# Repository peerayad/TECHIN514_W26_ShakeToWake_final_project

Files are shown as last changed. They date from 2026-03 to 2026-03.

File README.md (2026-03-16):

# TECHIN514_W26 Final Project
# Shake to Wake

> An alarm clock that **forces you out of bed** — the alarm won't stop until you've moved enough

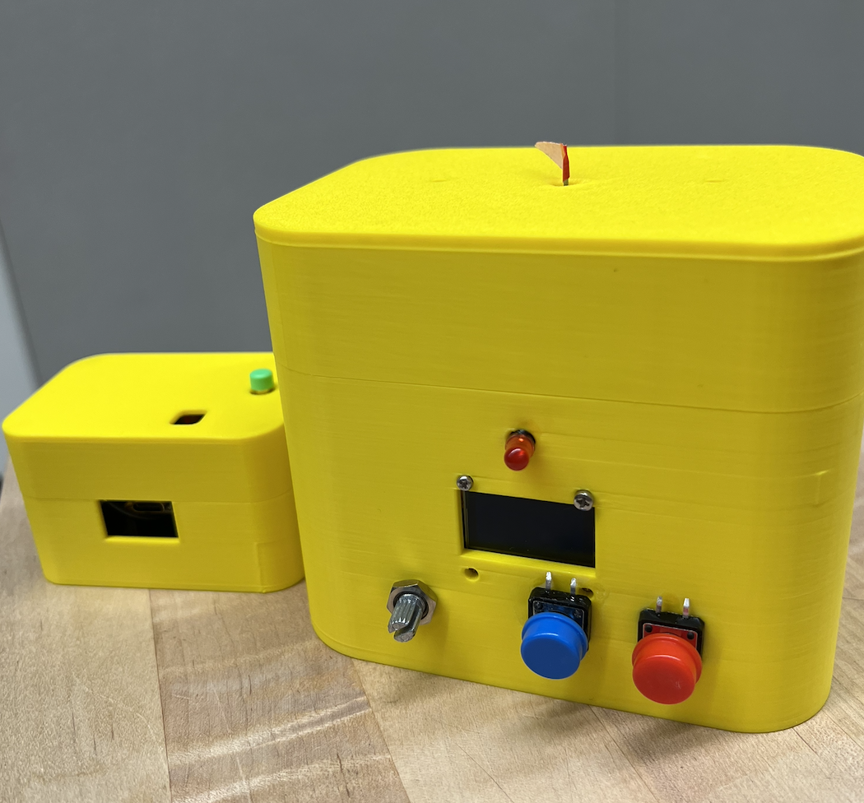
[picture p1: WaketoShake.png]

---

## 📦 Repository Structure
 
```
smart-alarm-clock/
├── alarm_unit/                  # Bedside alarm unit firmware (XIAO ESP32-C3)
│   ├── src/main.cpp
│   └── platformio.ini
├── sensor_unit/                 # sensor firmware (XIAO ESP32-C3)
│   ├── src/main.cpp
│   └── platformio.ini
├── datasheet/                   # Component datasheets
│   ├── ADXL345.pdf
│   ├── LED.pdf
│   ├── Passive_Buzzer.pdf
│   ├── Potentiometer.pdf
│   ├── Push_button.pdf
│   ├── SSD1306.pdf
│   ├── Tactile_switch.pdf
│   └── X27.pdf
├── hardware/
│   ├── Files/                   # Source design files
│   │   ├── Disclosure/          # Disclosure documents
│   │   ├── PCB/                 # KiCad PCB layout files
│   │   ├── Schematic/           # KiCad schematic files
│   │   └── BOM.numbers          # Bill of Materials
│   └── Picture/                 # Rendered images
│       ├── BOM.png
│       ├── Display_3D.png
│       ├── Display_circuit.png
│       ├── Display_disclosure.png
│       ├── PCB layput.png
│       ├── Schematic.png
│       ├── Sensor_3D.png
│       ├── Sensor_circuit.png
│       └── Sensor_disclosure.png
└── README.md
```

---

## 🔧 Hardware Overview

### Device 1 — Motion Sensor

A  sensor device that detects motion and transmits data wirelessly to the bedside alarm unit via ESP-NOW.

| Component | Part | Notes |
|---|---|---|
| Microcontroller | Seeed Studio XIAO ESP32-C3 | ESP-NOW wireless TX |
| Accelerometer | ADXL345 3-axis | Motion detection via I²C |
| Battery | 3.7V 500mAh LiPo

**How it works:**
1. ADXL345 reads 3-axis acceleration every 100ms
2. Adaptive DSP pipeline processes raw data:
   - **Delta Magnitude** — L1-norm: `|ΔX| + |ΔY| + |ΔZ|`
   - **SMA Filter (N=10)** — 10-sample rolling average, removes sensor noise
   - **Baseline Calibration** — collects 10 samples at alarm start, computes `threshold = μ + 3σ`
   - **Adaptive Threshold** — auto-calibrated per device and orientation
3. Broadcasts motion packet to alarm unit via ESP-NOW every 100ms

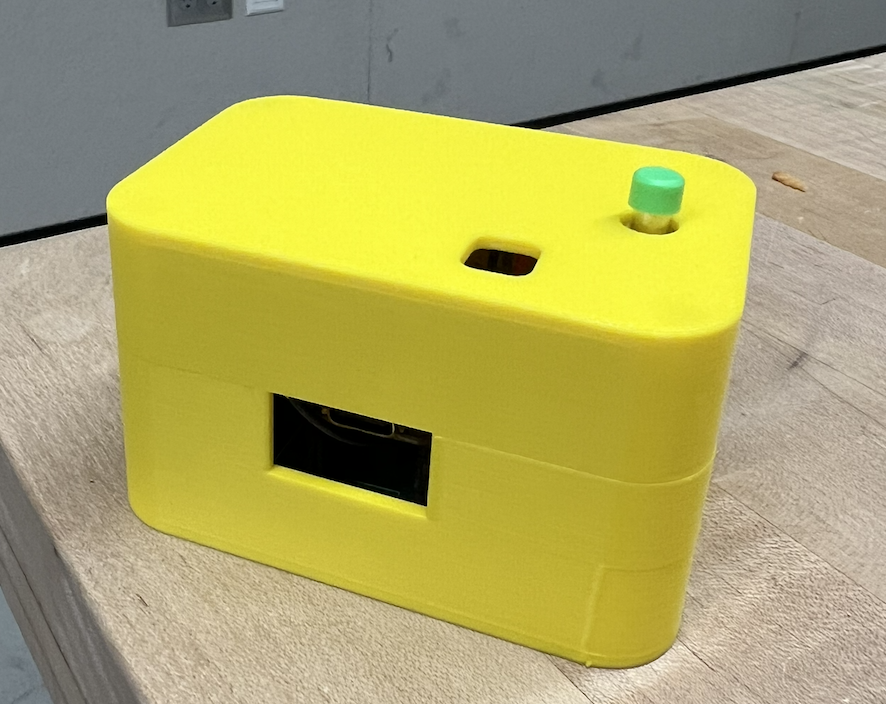
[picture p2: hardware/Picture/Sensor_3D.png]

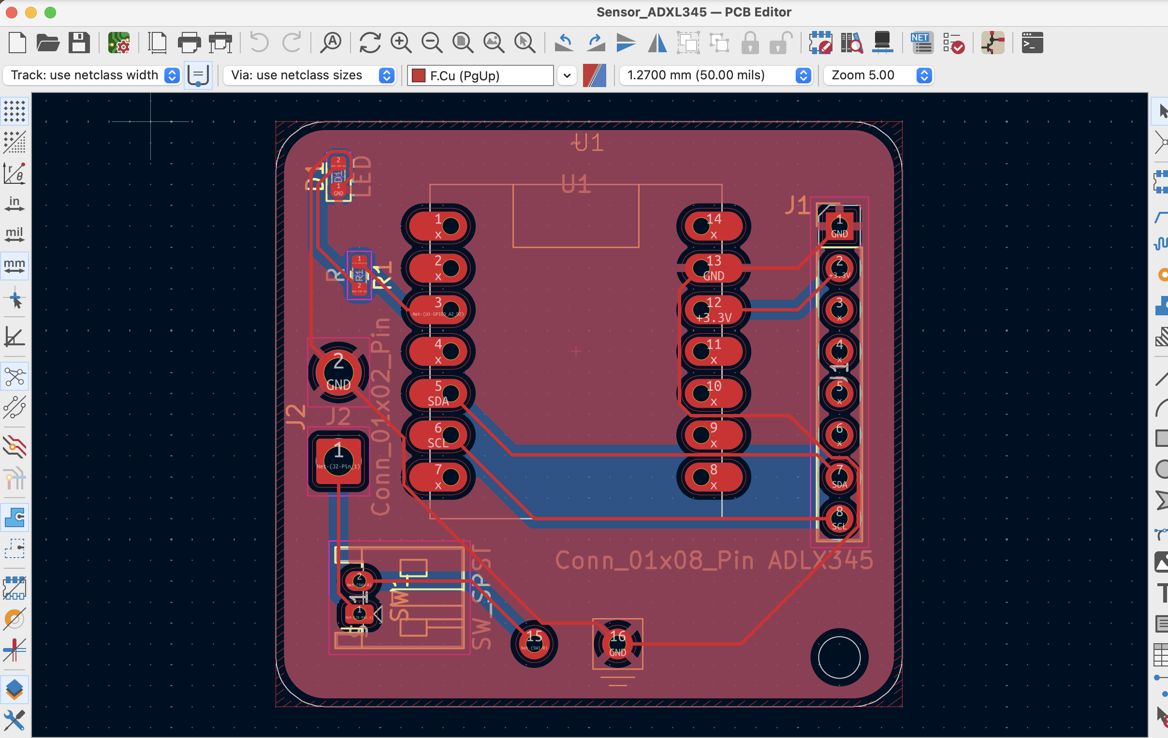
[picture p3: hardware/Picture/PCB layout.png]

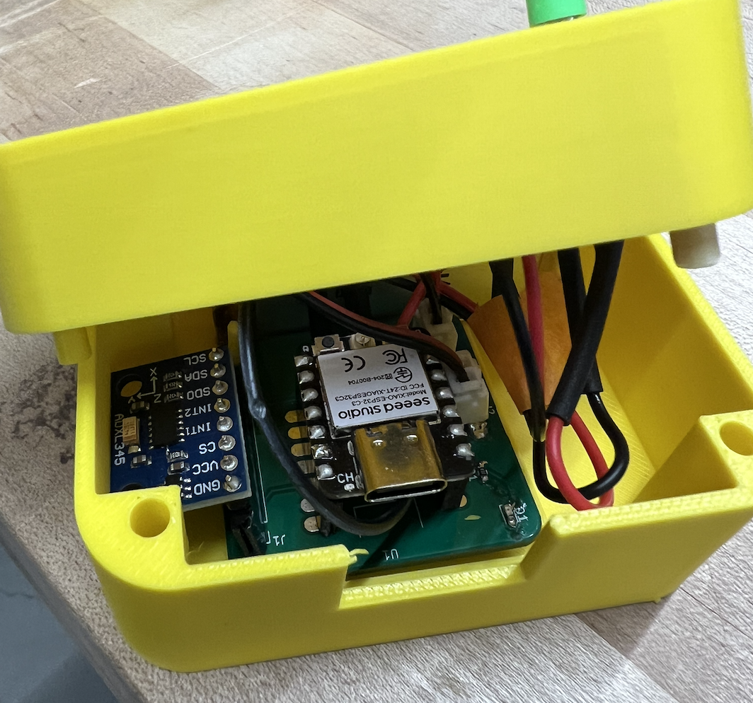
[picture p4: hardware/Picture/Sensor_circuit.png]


**Power:**
- 3.7V 500mAh LiPo → ~17h full-active but It will be used only 1 times per day and around 1-3 min. So It can last longer than one week.

---

### Device 2 — Bedside Alarm Unit

The bedside unit alerts the user at the scheduled time and tracks motion progress received from the sensor.

| Component | Part | Notes |
|---|---|---|
| Microcontroller | Seeed Studio XIAO ESP32-C3 | ESP-NOW receiver |
| Display | SSD1306 OLED 128×64 | I²C @ GPIO6(SDA) / GPIO7(SCL) |
| Gauge Motor | X27 / VID28-05 stepper | SwitecX25 library, 315° sweep |
| Buzzer | Passive piezo | Für Elise melody via LEDC PWM |
| LED | Single indicator | Blinks during alarm |
| Buttons | Tactile push button × 2 | ENTER (D9) / CANCEL (D8) |
| Potentiometer | B10K | Menu navigation |
| Power | USB-C 5V mains | Always-on bedside device |

**How it works:**
1. At scheduled alarm time: buzzer plays Für Elise, LED blinks, OLED shows `!! ALARM !!`
2. ESP-NOW initialises and connects to sensor
3. Sensor calibrates for 1 second → OLED shows `Calibrated!`
4. Motion detected → progress bar +10%, motor advances
5. X27 motor visually tracks progress (0° → 315° over 10 increments)
6. Alarm stops **only** when progress reaches 100%
7. Motor returns to 0°, ESP-NOW disconnects

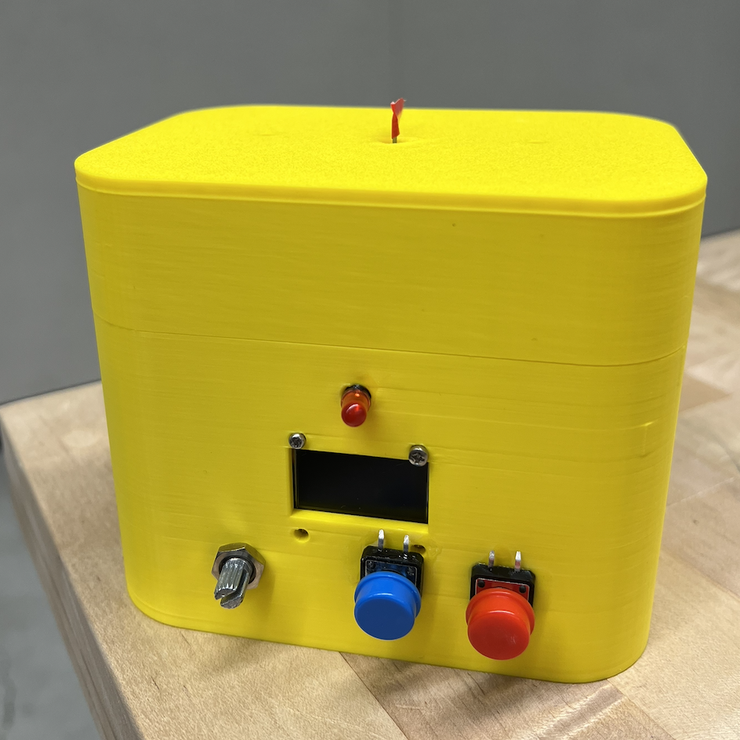
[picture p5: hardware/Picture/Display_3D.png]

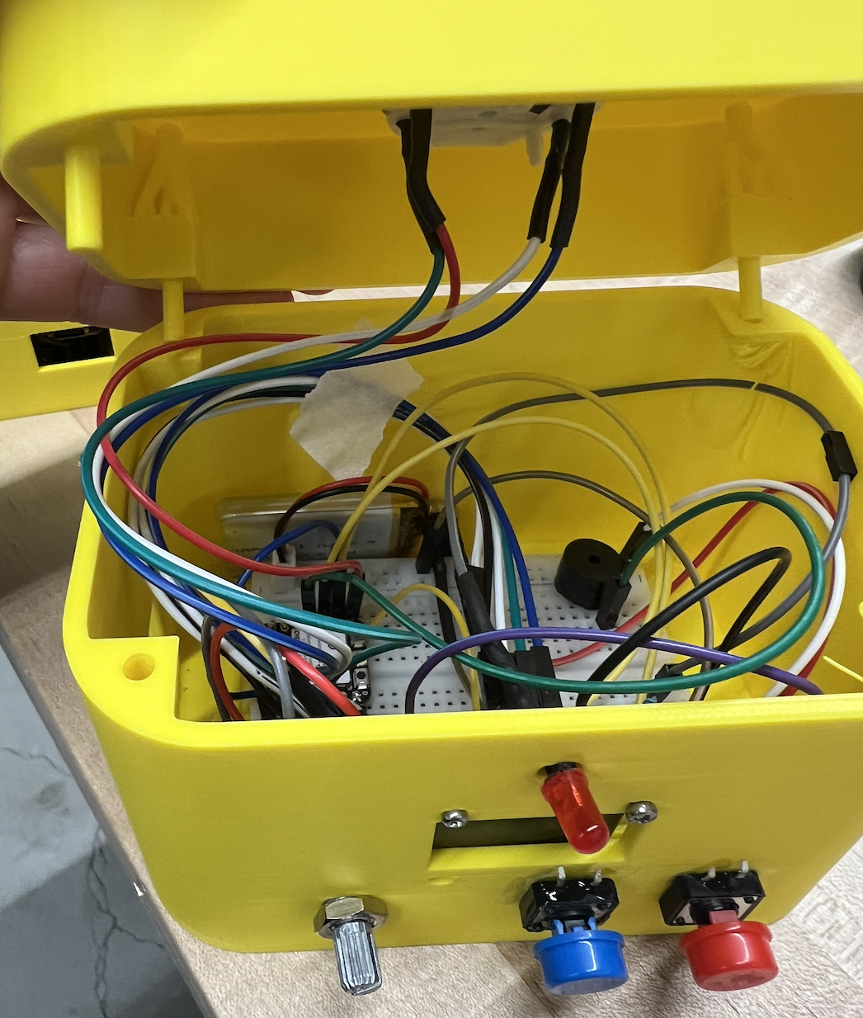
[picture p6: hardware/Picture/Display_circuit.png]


**User Interaction:**
- ENTER: set clock / alarm time via potentiometer
- CANCEL: force-stop alarm (only after 50% progress)
- Alarm **cannot** be fully dismissed until motion condition is satisfied

---

## 📡 System Architecture

```
┌──────────────────────────┐              ┌──────────────────────────┐
│   ..... SENSOR           │              │   BEDSIDE ALARM UNIT     │
│   XIAO ESP32-C3          │   ESP-NOW    │   XIAO ESP32-C3          │
│                          │  2.4 GHz     │                          │
│  ADXL345 → DSP → TX ────┼─────────────►│  RX → Progress Logic    │
│                          │              │                          │
│  500mAh LiPo             │              │  OLED + X27 Motor        │
│  USB-C charge            │              │  Buzzer + LED + Buttons  │
│                          │              │  USB-C mains             │
└──────────────────────────┘              └──────────────────────────┘

Protocols: I²C (ADXL345, OLED) | GPIO (Motor, LED, Buzzer) | ADC (Pot)
```

---

## 🔄 Workflow

```
1. Alarm time reached
        │
        ▼
2. Buzzer (Für Elise) + LED blink + OLED "!! ALARM !!" activated
        │
        ▼
3. ESP-NOW starts → connects to  sensor
        │
        ▼
4. Calibrate baseline (~1s, hold still) → "Calibrated!" on OLED
        │
        ▼
5. User moves sensor
        │
   ┌────┴──────────────────────┐
   │  Motion detected?          │
   │  smoothMag > μ + 3σ        │
   └────┬──────────────────────┘
        │ YES                    NO → progress holds
        ▼
6. Progress +10%, motor advances ~31.5°
        │
        ▼
7. Progress = 100% (10 increments)
        │
        ▼
8. Alarm stops, motor returns to 0°, ESP-NOW disconnects
```

---

## 📐 DSP Signal Processing Pipeline

The sensor uses an **Adaptive DSP pipeline** — threshold self-calibrates at each alarm onset:

| Step | Technique | Detail |
|---|---|---|
| 1 | Read XYZ @ 100ms | ADXL345 → I²C → ESP32-C3 |
| 2 | Delta Magnitude | L1-norm: `\|ΔX\|+\|ΔY\|+\|ΔZ\|` |
| 3 | SMA Filter (N=10) | Rolling average — removes sensor noise |
| 4 | Baseline Calibration | 10 samples at boot → compute μ and σ |
| 5 | Adaptive Threshold | `threshold = μ + 3σ` (auto per-device) |
| 6 | Cooldown Gate | 500ms temporal filter — prevents double-count |

**Accuracy (50 trials):**
- True Positive Rate: **96.4%** (after adaptive calibration)
- False Positive Rate: **1.8%** (vs 5.8% with fixed threshold)
- Calibration time: **~1 second**

---

## 🔋 Power Considerations
 
### Sensor Unit — 3.7V 500mAh LiPo
 
| Parameter | Calculation | Value |
|---|---|---|
| Usage per day | Alarm time | 15 min (0.25h) |
| Standby time/day | 24h − 0.25h | 23.75h |
| Standby energy | 6.73 mW × 23.75h | 159.8 mWh |
| Alarm energy | 95.4 mW × 0.25h | 23.8 mWh |
| **Energy per day** | 159.8 + 23.8 | **183.6 mWh** |
| Battery needed (1 week) | 1,285 mWh ÷ (3.7 × 0.85) | 409 mAh |
| **Battery chosen** | Standard LiPo | **500 mAh ✅** |
| **Battery life** | 1,572 mWh ÷ 183.6 mWh/day | **~7.6 days** |
 
| Metric | Value |
|---|---|
| Active Draw (alarming) | ~25.8 mA |
| Sleep Draw (standby) | ~1.8 mA |
| Charging | USB-C, ~1h |

See more detail in [Battery Consideration](hardware/Files/ShakeToWake_BatterySizing.xlsx)

---

## 💰 Bill of Materials (Budgeting)

| Component | Qty | Unit | Total |
|---|---|---|---|
| XIAO ESP32-C3 | 2 | $7.00 | $14.00 |
| ADXL345 Module | 1 | $2.50 | $2.50 |
| SSD1306 OLED 0.96" | 1 | $3.50 | $3.50 |
| X27 / VID28-05 Motor | 1 | $4.00 | $4.00 |
| Passive Buzzer | 1 | $0.50 | $0.50 |
| LED + Resistors | — | $0.20 | $0.20 |
| Tactile Button × 2 | 2 | $0.30 | $0.60 |
| B10K Potentiometer | 1 | $0.40 | $0.40 |
| LiPo 500mAh (sensor) | 1 | $3.50 | $3.50 |
| **TOTAL** | | | **$30.20** |

---

## 🛠️ Setup & Flash

### Requirements
- [PlatformIO](https://platformio.org/) (VS Code extension)
- Board: `seeed_xiao_esp32c3`

### Flash Alarm Unit
```bash
cd alarm_unit
pio run --target upload
```

### Flash Sensor Unit
```bash
cd sensor_unit
# ⚠️ Update ALARM_UNIT_MAC[] in src/main.cpp with alarm unit's MAC address
# Find MAC: open Serial Monitor on alarm unit at 115200 baud after boot
pio run --target upload
```

---

## 🚀 Future Work

Making a small wearable sensor on the leg and it can detect when user are actually walking to confirm whether the user has woken up or not. Since now the sensor device is too big to be attached on the body
---

## 📋 Schematic & PCB Layout

- KiCad schematic: [`hardware/schematic/`](hardware/Files/Schematic/)
- PCB layout: [`hardware/pcb/`](hardware/Files/PCB/)

---

## 📚 Course Information

**Course:** TECHIN514 — Embedded Systems  
**Term:** Winter 2026 (W26)  
**Project:** Final Project

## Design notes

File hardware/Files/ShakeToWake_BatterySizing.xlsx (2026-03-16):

Battery Sizing — Sensor Unit (XIAO ESP32-C3 + ADXL345)
Assumption: alarm 15 min/day | standby 23h 45min/day | 3.7V LiPo | 85% regulator efficiency
Parameter | Calculation | Value
Usage per day | Alarm time | 15 min (0.25h)
Standby time/day | 24h − 0.25h | 23.75 h
Standby energy | 6.73 mW × 23.75h | 159.8 mWh
Alarm energy | 95.4 mW × 0.25h | 23.8 mWh
Energy per day | 159.8 + 23.8 | 183.6 mWh
Target duration | 1 week | 7 days
Energy needed | 183.6 × 7 | 1,285 mWh
Battery needed | 1,285 ÷ (3.7 × 0.85) | 409 mAh
Battery chosen | Standard LiPo size | 500 mAh ✅
Actual battery life | 1,572 mWh ÷ 183.6 mWh/day | 7.6 days

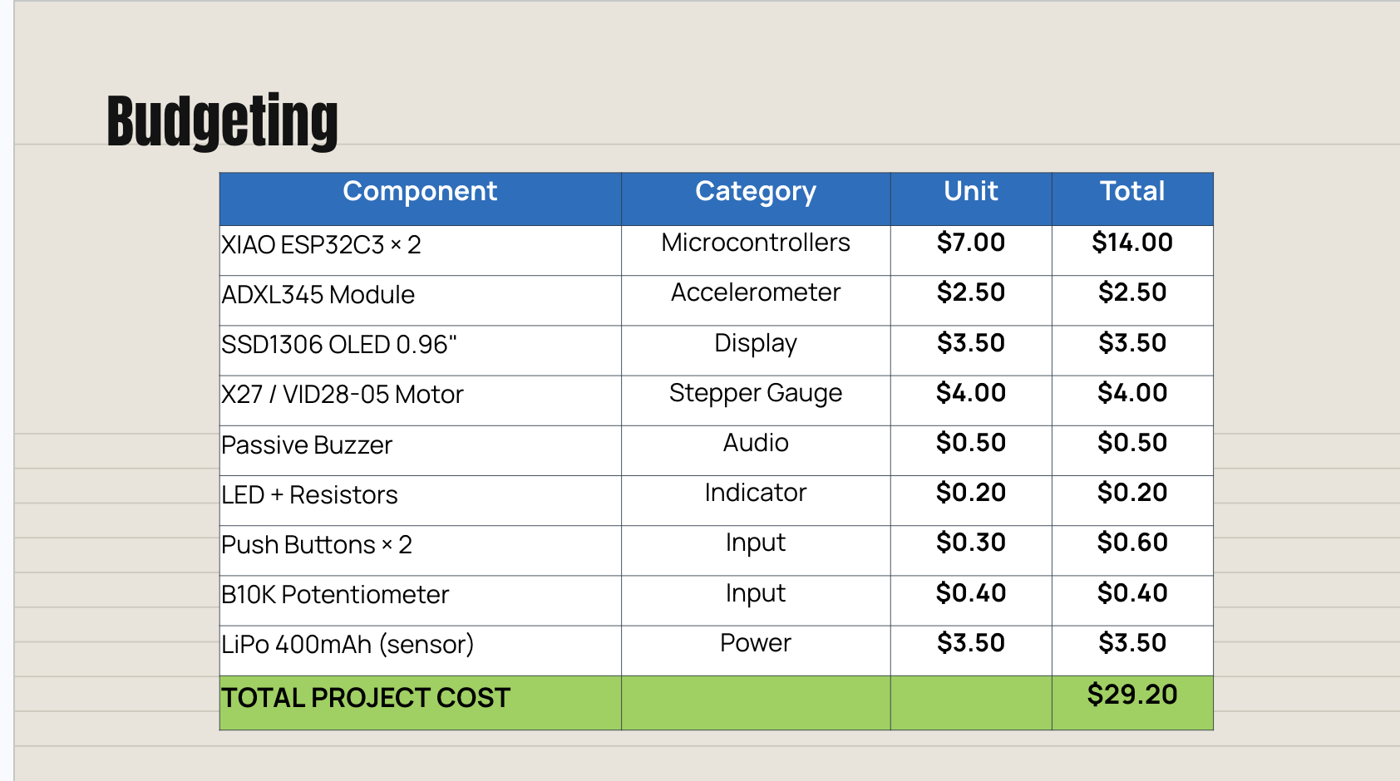
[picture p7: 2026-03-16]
hardware/Picture/Budgeting.png

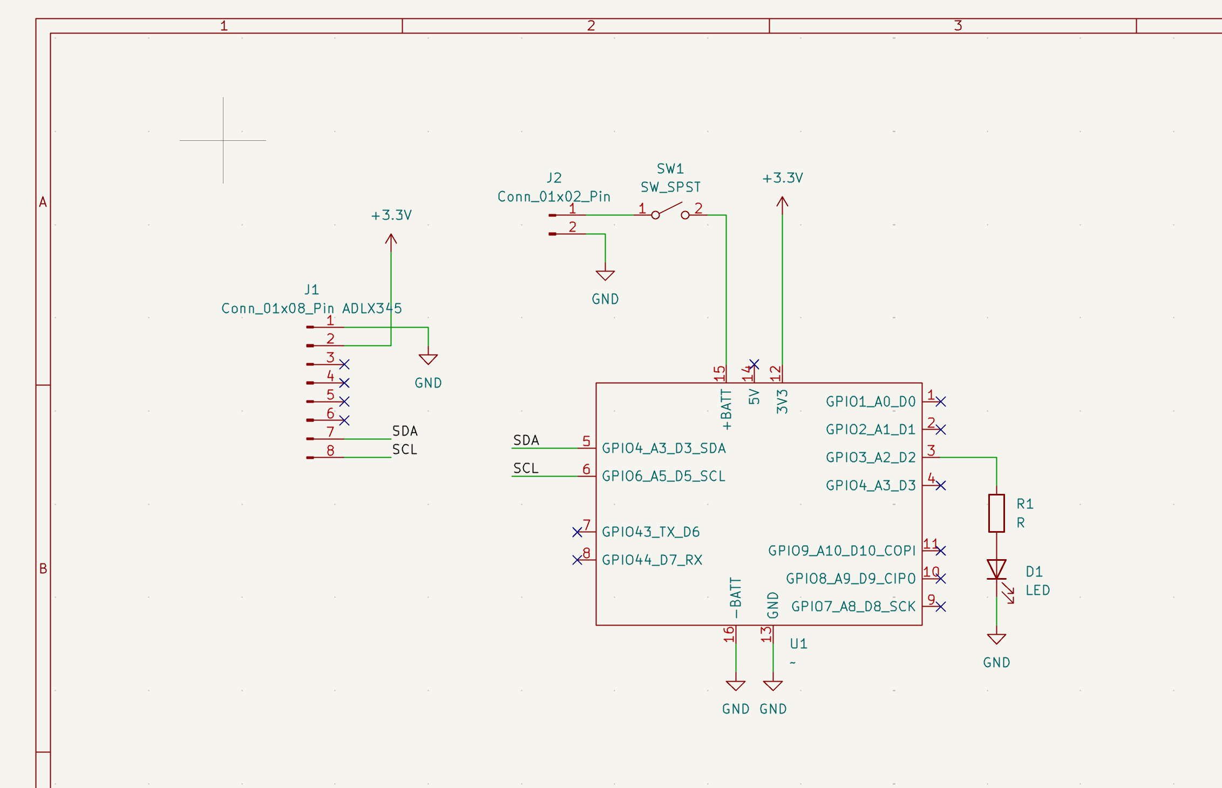
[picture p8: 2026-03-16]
hardware/Picture/Schematic.png

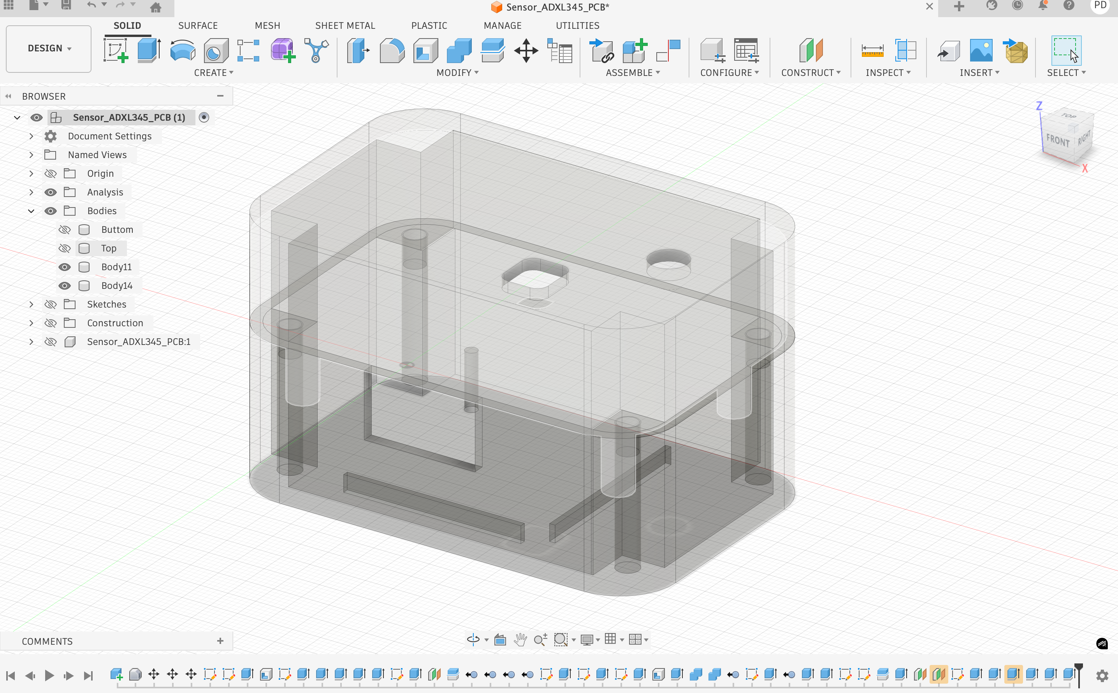
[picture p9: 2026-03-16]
hardware/Picture/Sensor_disclosure.png

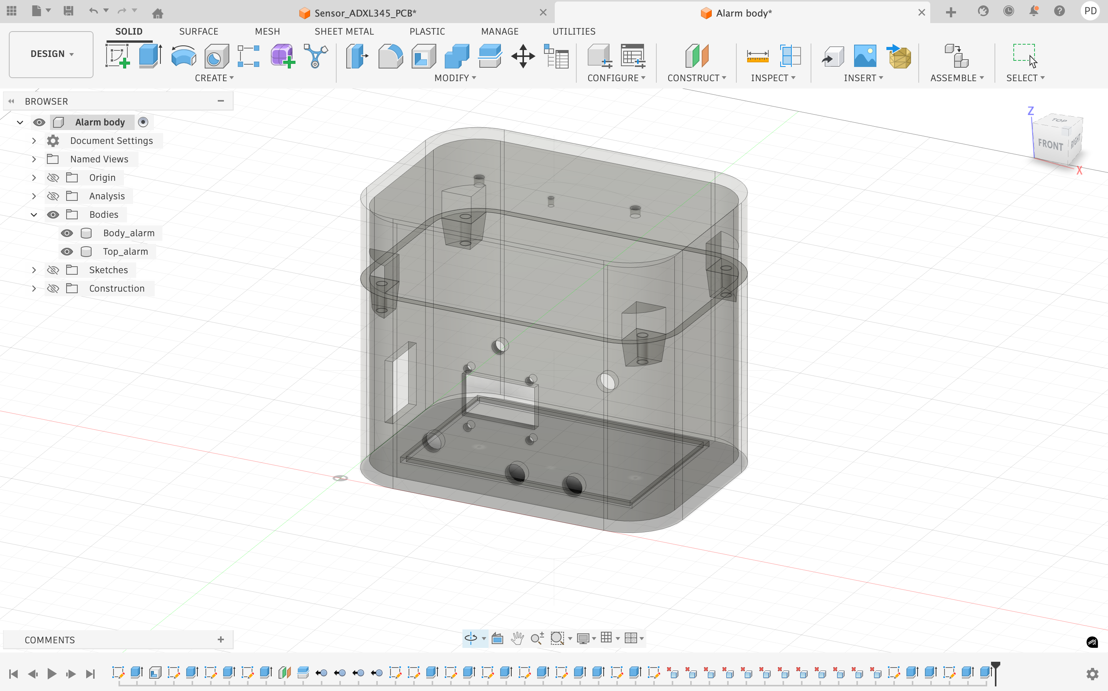
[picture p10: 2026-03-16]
hardware/Picture/Display_disclosure.png

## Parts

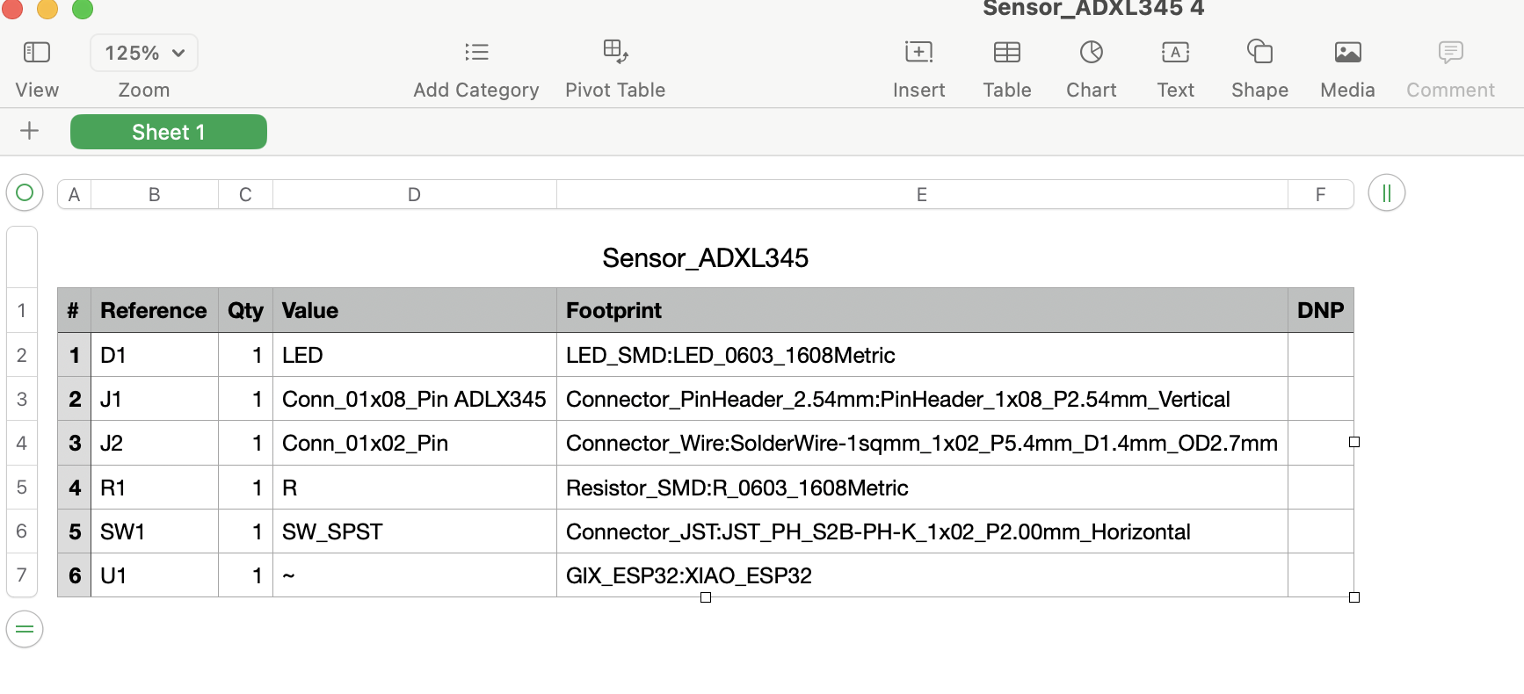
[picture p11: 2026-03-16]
hardware/Picture/BOM.png

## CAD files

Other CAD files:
hardware/Files/Disclosure/Display_disclosure.f3d
hardware/Files/Disclosure/Sensor_disclosure.f3d

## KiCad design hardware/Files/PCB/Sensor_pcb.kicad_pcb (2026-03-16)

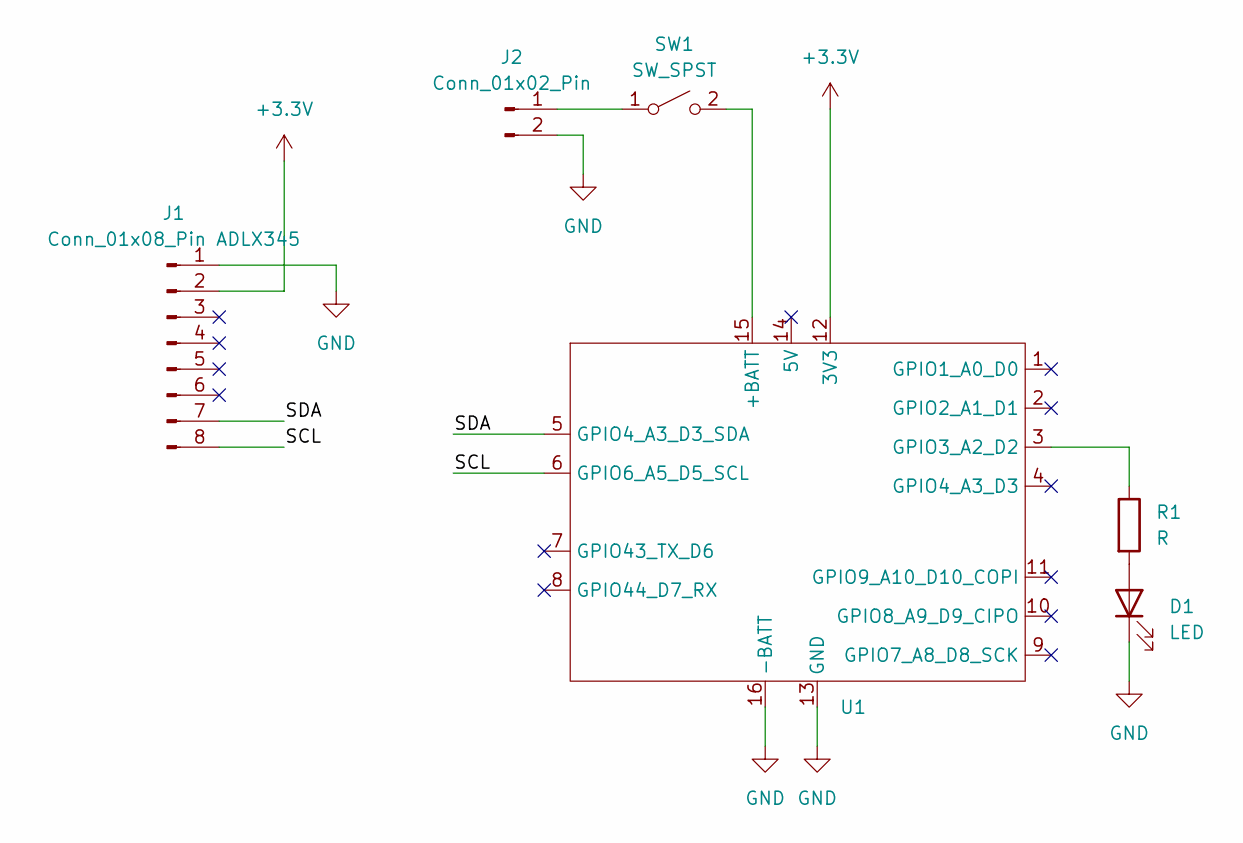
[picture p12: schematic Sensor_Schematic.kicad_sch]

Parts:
D1: LED; LED_0603_1608Metric
J1: Conn_01x08_Pin ADLX345; PinHeader_1x08_P2.54mm_Vertical
J2: Conn_01x02_Pin; SolderWire-1sqmm_1x02_P5.4mm_D1.4mm_OD2.7mm
R1: R; R_0603_1608Metric
SW1: SW_SPST; JST_PH_S2B-PH-K_1x02_P2.00mm_Horizontal
U1: XIAO_ESP32

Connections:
+3.3V: J1.2, U1.12 (3V3)
/SCL: J1.8, U1.6 (GPIO6_A5_D5_SCL)
/SDA: J1.7, U1.5 (GPIO4_A3_D3_SDA)
GND: D1.1 (K), J1.1, J2.2, U1.13 (GND), U1.16 (-BATT)
unnamed: D1.2 (A), R1.2
unnamed: J2.1, SW1.1 (A)
unnamed: SW1.2 (B), U1.15 (+BATT)
unnamed: R1.1, U1.3 (GPIO3_A2_D2)

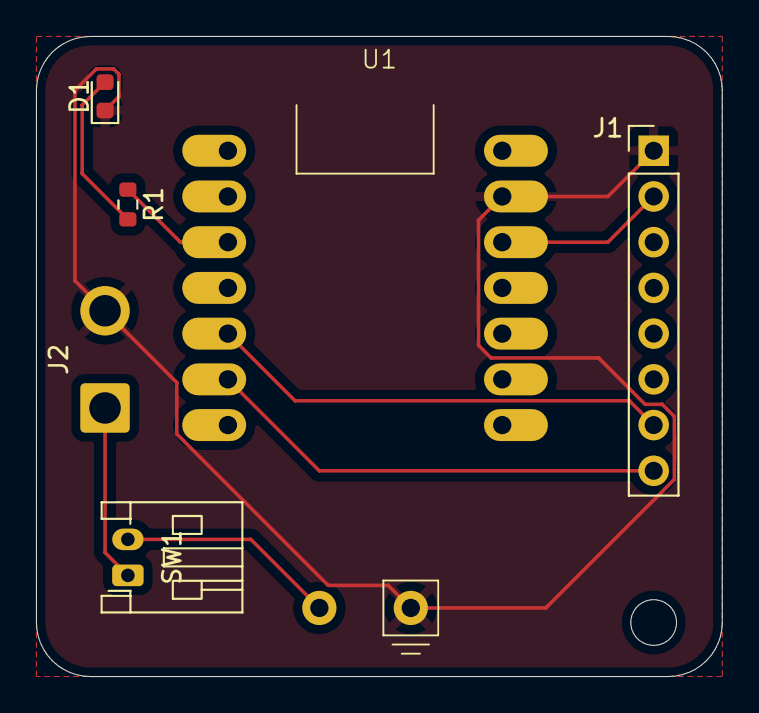
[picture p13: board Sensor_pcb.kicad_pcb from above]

Board: 2 copper layers, 38.1 x 35.6 mm, 6 parts (0 on the bottom side), 8 nets.

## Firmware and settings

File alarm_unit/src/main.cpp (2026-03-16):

/**
 * ============================================================
 *  ESP-NOW RECEIVER + ALARM CLOCK
 *  XIAO ESP32C3 — OLED + X27 Motor + LED + Buzzer + 2 Buttons + B10K Pot
 * ============================================================
 */

#include <Arduino.h>
#include <Wire.h>
#include <WiFi.h>
#include <esp_now.h>
#include <Adafruit_GFX.h>
#include <Adafruit_SSD1306.h>
#include <SwitecX25.h>

// ─── Pin Definitions ────────────────────────────────────────
#define BTN_ENTER   D9
#define BTN_CANCEL  D8
#define LED_PIN     D6
#define BUZZER_PIN  D10
#define POT_PIN     D0
#define M1  D1
#define M2  D2
#define M3  D3
#define M4  D7

// ─── OLED ───────────────────────────────────────────────────
#define SCREEN_W  128
#define SCREEN_H   64
#define OLED_ADDR 0x3C
Adafruit_SSD1306 display(SCREEN_W, SCREEN_H, &Wire, -1);

// ─── Data struct ────────────────────────────────────────────
typedef struct struct_message { float x, y, z; } struct_message;
struct_message incomingData;

// ─── ESP-NOW State ───────────────────────────────────────────
float gX=0, gY=0, gZ=0;
bool  espnowActive=false, espnowConnected=false;
unsigned long lastDataMs=0;
#define ESPNOW_TIMEOUT_MS 2000

// ─── State Machine ───────────────────────────────────────────
enum AppState { STATE_SHOW, STATE_MENU, STATE_SET_H, STATE_SET_M, STATE_SET_AMPM, STATE_ALARMING };
AppState appState = STATE_SHOW;

// ─── Clock & Alarm ───────────────────────────────────────────
int clkH=0, clkM=0, clkS=50, almH=0, almM=1;
bool almEnabled=true, editAM=true, editingClock=true;
int  editH=12, editM=0, menuSel=0;
unsigned long lastSecMillis=0, lastDisplayMillis=0, alarmStartMillis=0;
#define ALARM_TIMEOUT_MS 60000
float prevGX=0, prevGY=0, prevGZ=0;

// ─── Adaptive DSP ────────────────────────────────────────────
#define SMA_WINDOW       10
#define CALIB_SAMPLES    10
#define CALIB_SIGMA_MULT 2.5f  // balanced between sensitive and stable
float smaBuffer[SMA_WINDOW]={0};
int   smaIdx=0;
float calibMean=1.5f, calibThreshold=1.5f;
bool  calibDone=false;
int   calibCount=0;

float smaUpdate(float v){
    smaBuffer[smaIdx%SMA_WINDOW]=v; smaIdx++;
    float s=0; for(int i=0;i<SMA_WINDOW;i++) s+=smaBuffer[i];
    return s/SMA_WINDOW;
}

int  to12h(int h){ return (h%12==0)?12:h%12; }
bool isAM(int h) { return h<12; }
int  to24h(int h,bool am){ if(am) return (h==12)?0:h; else return (h==12)?12:h+12; }

// ─── X27 Motor ───────────────────────────────────────────────
#define MOTOR_MAX              600
#define MOTOR_STEP              60
#define MOTOR_STEP_COOLDOWN_MS 500
SwitecX25 motor(MOTOR_MAX, M1, M2, M3, M4);
int motorProgress=0;
unsigned long lastMotorStepMs=0;

// ── Blocking return to physical 0 ────────────────────────────
void motorReset() {
    motorProgress = 0;

    // Show on OLED while returning
    display.clearDisplay();
    display.setTextColor(SSD1306_WHITE);
    display.setTextSize(2);
    display.setCursor(4, 18);
    display.print("Returning");
    display.setCursor(4, 38);
    display.print("to zero..");
    display.display();

    Serial.printf("[MOTOR] Returning from step %d to 0\n", motor.currentStep);

    // Force target = 0 and step until physically there
    // Use targetStep check too in case currentStep already reads 0
    motor.setPosition(0);
    unsigned long t = millis();
    while ((motor.currentStep != 0 || motor.targetStep != 0) && millis()-t < 10000UL) {
        motor.update();
    }

    Serial.println("[MOTOR] At zero");

    display.clearDisplay();
    display.setTextSize(2);
    display.setCursor(28, 24);
    display.print("Done!");
    display.display();
    delay(500);
}

// ─── ESP-NOW ─────────────────────────────────────────────────
void OnDataRecv(const uint8_t*, const uint8_t*, int);

void espnowStart(){
    if(espnowActive) return;
    WiFi.mode(WIFI_STA); WiFi.disconnect();
    if(esp_now_init()!=ESP_OK){ Serial.println("[ESP-NOW] FAILED"); return; }
    esp_now_register_recv_cb(OnDataRecv);
    espnowActive=true; espnowConnected=false; lastDataMs=0; gX=gY=gZ=0;
    Serial.println("[ESP-NOW] Started");
}
void espnowStop(){
    if(!espnowActive) return;
    esp_now_deinit(); WiFi.mode(WIFI_OFF);
    espnowActive=false; espnowConnected=false;
    Serial.println("[ESP-NOW] Stopped");
}

// ─── LED ─────────────────────────────────────────────────────
void updateStatusLed(){
    if(appState==STATE_ALARMING) return;
    digitalWrite(LED_PIN, LOW);
}

// ─── Buzzer – Für Elise ──────────────────────────────────────
#define BUZZER_CH 0
void buzzerTone(int f){
    if(f<=0){ ledcDetachPin(BUZZER_PIN); digitalWrite(BUZZER_PIN,LOW); return; }
    ledcSetup(BUZZER_CH,f,8); ledcAttachPin(BUZZER_PIN,BUZZER_CH); ledcWrite(BUZZER_CH,128);
}
void buzzerOff(){ ledcDetachPin(BUZZER_PIN); digitalWrite(BUZZER_PIN,LOW); }

const int FE_NOTES[]={659,623,659,623,659,494,587,523,440,0,262,330,440,494,0,330,415,494,523,0,330,659,623,659,623,659,494,587,523,440,0};
const int FE_DURS[] ={120,120,120,120,120,120,120,120,240,120,120,120,120,240,120,120,120,120,240,120,120,120,120,120,120,120,120,120,120,120,240,360};
const int FE_LEN=sizeof(FE_NOTES)/sizeof(FE_NOTES[0]);
int feIdx=0; unsigned long lastNoteMs=0;

void buzzerUpdate(){
    if(appState!=STATE_ALARMING) return;
    if(millis()-lastNoteMs<(unsigned long)FE_DURS[feIdx]) return;
    feIdx=(feIdx+1)%FE_LEN; lastNoteMs=millis();
    buzzerTone(FE_NOTES[feIdx]);
}

// ─── ESP-NOW Receive ─────────────────────────────────────────
void OnDataRecv(const uint8_t *mac, const uint8_t *data, int len){
    if(len!=sizeof(struct_message)) return;
    memcpy(&incomingData,data,sizeof(incomingData));
    gX=incomingData.x; gY=incomingData.y; gZ=incomingData.z;
    lastDataMs=millis(); espnowConnected=true;
    Serial.printf("[RECV] X=%.2f Y=%.2f Z=%.2f\n",gX,gY,gZ);

    if(appState==STATE_ALARMING){
        float dX=fabsf(gX-prevGX);
        float dY=fabsf(gY-prevGY);
        float dZ=fabsf(gZ-prevGZ);
        float rawMag=dX+dY+dZ;
        float smoothMag=smaUpdate(rawMag);

        static float calibBuf[CALIB_SAMPLES];
        if(!calibDone){
            if(calibCount<CALIB_SAMPLES){
                calibBuf[calibCount++]=smoothMag;
                Serial.printf("[CALIB] %d/%d\n",calibCount,CALIB_SAMPLES);
            } else {
                float sum=0; for(int i=0;i<CALIB_SAMPLES;i++) sum+=calibBuf[i];
                calibMean=sum/CALIB_SAMPLES;
                float var=0;
                for(int i=0;i<CALIB_SAMPLES;i++){ float d=calibBuf[i]-calibMean; var+=d*d; }
                float sigma=sqrtf(var/CALIB_SAMPLES);
                calibThreshold=calibMean+CALIB_SIGMA_MULT*sigma;

                // Safety cap — threshold must be between 0.3g and 2.0g
                // Prevents bad calibration (moving during calib) locking out alarm
                if(calibThreshold < 0.6f) calibThreshold = 0.6f;  // min 0.6g prevents idle false positive
                if(calibThreshold > 2.0f) calibThreshold = 2.0f;

                calibDone=true;
                Serial.printf("[CALIB] Done! mean=%.3f sigma=%.3f thr=%.3f\n",calibMean,sigma,calibThreshold);
                display.clearDisplay();
                display.setTextColor(SSD1306_WHITE);
                display.setTextSize(2); display.setCursor(4,20); display.print("Calibrated!");
                display.setTextSize(1); display.setCursor(4,44); display.printf("thr=%.2fg",calibThreshold);
                display.display(); delay(1000);
            }
            prevGX=gX; prevGY=gY; prevGZ=gZ;
            return;
        }

        bool moving = smoothMag > calibThreshold;
        Serial.printf("[DSP] raw=%.3f smooth=%.3f thr=%.3f moving=%d\n",rawMag,smoothMag,calibThreshold,moving);

        if(moving && millis()-lastMotorStepMs>=MOTOR_STEP_COOLDOWN_MS){
            motorProgress+=MOTOR_STEP;
            if(motorProgress>MOTOR_MAX) motorProgress=MOTOR_MAX;
            motor.setPosition(motorProgress);
            lastMotorStepMs=millis();
            Serial.printf("[ALARM] Progress: %d/%d (%d%%)\n",motorProgress,MOTOR_MAX,map(motorProgress,0,MOTOR_MAX,0,100));
        }
    }
    prevGX=gX; prevGY=gY; prevGZ=gZ;
}

// ─── Clock Tick ──────────────────────────────────────────────
void clockTick(){
    unsigned long now=millis();
    if(now-lastSecMillis<1000) return;
    lastSecMillis+=1000;
    if(now-lastSecMillis>2000) lastSecMillis=now;
    if(++clkS>=60){clkS=0; if(++clkM>=60){clkM=0; if(++clkH>=24) clkH=0;}}
    if(espnowActive) espnowConnected=(millis()-lastDataMs<ESPNOW_TIMEOUT_MS);
    if(almEnabled && appState==STATE_SHOW && clkH==almH && clkM==almM && clkS==0){
        appState=STATE_ALARMING; alarmStartMillis=now;
        motorProgress=0; lastMotorStepMs=0;
        motor.setPosition(0);
        feIdx=0; lastNoteMs=0;
        prevGX=prevGY=prevGZ=0;
        calibDone=false; calibCount=0;
        espnowStart();
        Serial.println("[ALARM] Triggered");
    }
}

// ─── Buttons ─────────────────────────────────────────────────
volatile bool enterPressed=false, cancelPressed=false;
unsigned long lastEnterMs=0, lastCancelMs=0;
#define DEBOUNCE_MS 50
void IRAM_ATTR isrEnter() { if(millis()-lastEnterMs>DEBOUNCE_MS){ enterPressed=true; lastEnterMs=millis(); } }
void IRAM_ATTR isrCancel(){ if(millis()-lastCancelMs>DEBOUNCE_MS){ cancelPressed=true; lastCancelMs=millis(); } }

// ─── Pot ─────────────────────────────────────────────────────
static int potPrev=-1; static unsigned long lastPotMove=0;
#define POT_DEADBAND 80
#define POT_DELAY_MS 150
void readPot(){
    if(appState==STATE_SHOW||appState==STATE_ALARMING) return;
    int r=0; for(int i=0;i<4;i++) r+=analogRead(POT_PIN); r/=4;
    if(potPrev<0){potPrev=r; return;}
    int diff=r-potPrev;
    if(abs(diff)<POT_DEADBAND) return;
    if(millis()-lastPotMove<POT_DELAY_MS) return;
    int dir=(diff>0)?1:-1; potPrev=r; lastPotMove=millis();
    switch(appState){
        case STATE_MENU:     menuSel=constrain(menuSel+dir,0,1); break;
        case STATE_SET_H:    editH=constrain(editH+dir,1,12);    break;
        case STATE_SET_M:    editM=(editM+dir+60)%60;             break;
        case STATE_SET_AMPM: editAM=!editAM;                     break;
        default: break;
    }
}

// ─── State Transitions ───────────────────────────────────────
void handleInput(){
    if(!enterPressed&&!cancelPressed) return;
    switch(appState){
        case STATE_SHOW:
            if(enterPressed){ menuSel=0; appState=STATE_MENU; } break;
        case STATE_MENU:
            if(enterPressed){
                editingClock=(menuSel==0);
                int sH=editingClock?clkH:almH, sM=editingClock?clkM:almM;
                editH=to12h(sH); editM=sM; editAM=isAM(sH); appState=STATE_SET_H;
            }
            if(cancelPressed) appState=STATE_SHOW; break;
        case STATE_SET_H:
            if(enterPressed)  appState=STATE_SET_M;
            if(cancelPressed) appState=STATE_MENU; break;
        case STATE_SET_M:
            if(enterPressed)  appState=STATE_SET_AMPM;
            if(cancelPressed) appState=STATE_SET_H; break;
        case STATE_SET_AMPM:
            if(enterPressed){
                int h24=to24h(editH,editAM);
                if(editingClock){clkH=h24;clkM=editM;clkS=0;lastSecMillis=millis();}
                else {almH=h24;almM=editM;almEnabled=true;}
                appState=STATE_SHOW;
            }
            if(cancelPressed) appState=STATE_SET_M; break;
        case STATE_ALARMING:
            // Stop alarm immediately, then motor returns, then WiFi off
            buzzerOff();
            digitalWrite(LED_PIN,LOW);
            almEnabled=false;
            appState=STATE_SHOW;   // switch state first so OLED shows "Returning"
            motorReset();          // blocking — shows "Returning to zero.."
            espnowStop();
            Serial.println("[ALARM] Dismissed by button");
            break;
    }
    enterPressed=cancelPressed=false;
}

// ─── Alarm Effects ───────────────────────────────────────────
void alarmEffects(){
    if(appState!=STATE_ALARMING) return;
    if(millis()-alarmStartMillis>ALARM_TIMEOUT_MS){
        buzzerOff(); digitalWrite(LED_PIN,LOW); almEnabled=false;
        appState=STATE_SHOW;
        motorReset(); espnowStop();
        Serial.println("[ALARM] Timeout"); return;
    }
    if(motorProgress>=MOTOR_MAX && motor.currentStep==motor.targetStep){
        buzzerOff(); digitalWrite(LED_PIN,LOW); almEnabled=false;
        appState=STATE_SHOW;
        motorReset(); espnowStop();
        Serial.println("[ALARM] Done by motion"); return;
    }
    digitalWrite(LED_PIN,(millis()/300)%2?HIGH:LOW);
    buzzerUpdate();
}

// ─── Display ─────────────────────────────────────────────────
void drawStatusBadge(){
    display.setTextSize(1); display.setCursor(92,0);
    if(espnowConnected){ display.print("[NOW]"); }
    else {
        static uint8_t dots=0; static unsigned long ld=0;
        if(millis()-ld>400){dots=(dots+1)%4;ld=millis();}
        display.print("NOW"); for(int i=0;i<dots;i++) display.print(".");
    }
}
void drawShowTime(){
    display.setTextSize(2); display.setCursor(0,0);
    display.printf("%2d:%02d:%02d",to12h(clkH),clkM,clkS);
    display.setTextSize(1); display.setCursor(112,0); display.print(isAM(clkH)?"AM":"PM");
    display.setCursor(0,18); display.printf("A %2d:%02d%s %s",to12h(almH),almM,isAM(almH)?"AM":"PM",almEnabled?"ON ":"off");
    display.drawLine(0,27,127,27,SSD1306_WHITE);
    display.setCursor(0,54); display.print("[ ENTER = Setup ]");
}
void drawMenu(){
    display.setTextSize(1); display.setCursor(0,0); display.print("-- Setup --");
    display.drawLine(0,9,127,9,SSD1306_WHITE); display.setTextSize(2);
    if(menuSel==0){display.fillRoundRect(0,14,128,22,3,SSD1306_WHITE);display.setTextColor(SSD1306_BLACK);}
    else display.setTextColor(SSD1306_WHITE);
    display.setCursor(28,18); display.print("Clock"); display.setTextColor(SSD1306_WHITE);
    if(menuSel==1){display.fillRoundRect(0,38,128,22,3,SSD1306_WHITE);display.setTextColor(SSD1306_BLACK);}
    display.setCursor(28,42); display.print("Alarm"); display.setTextColor(SSD1306_WHITE);
    display.setTextSize(1); display.setCursor(0,56); display.print("Turn=Sel  ENT=OK  CAN=Back");
}
void drawSetH(){
    display.setTextSize(1); display.setCursor(0,0); display.print(editingClock?"Set Clock":"Set Alarm");
    display.drawLine(0,9,127,9,SSD1306_WHITE); display.setCursor(0,12); display.print("Hour  (1-12)");
    display.setTextSize(3); display.setCursor(4,22); display.printf("%2d:%02d",editH,editM);
    display.setTextSize(2); display.setCursor(98,26); display.print(editAM?"AM":"PM");
    display.drawLine(4,50,54,50,SSD1306_WHITE);
    display.setTextSize(1); display.setCursor(0,56); display.print("ENT=Next  CAN=Back");
}
void drawSetM(){
    display.setTextSize(1); display.setCursor(0,0); display.print(editingClock?"Set Clock":"Set Alarm");
    display.drawLine(0,9,127,9,SSD1306_WHITE); display.setCursor(0,12); display.print("Minute  (0-59)");
    display.setTextSize(3); display.setCursor(4,22); display.printf("%2d:%02d",editH,editM);
    display.setTextSize(2); display.setCursor(98,26); display.print(editAM?"AM":"PM");
    display.drawLine(58,50,110,50,SSD1306_WHITE);
    display.setTextSize(1); display.setCursor(0,56); display.print("ENT=Next  CAN=Back");
}
void drawSetAMPM(){
    display.setTextSize(1); display.setCursor(0,0); display.print(editingClock?"Set Clock":"Set Alarm");
    display.drawLine(0,9,127,9,SSD1306_WHITE);
    display.setTextSize(2); display.setCursor(14,13); display.printf("%2d:%02d %s",editH,editM,editAM?"AM":"PM");
    if(editAM){display.fillRoundRect(4,36,56,20,3,SSD1306_WHITE);display.setTextColor(SSD1306_BLACK);}
    display.setCursor(18,39); display.print("AM"); display.setTextColor(SSD1306_WHITE);
    if(!editAM){display.fillRoundRect(68,36,56,20,3,SSD1306_WHITE);display.setTextColor(SSD1306_BLACK);}
    display.setCursor(82,39); display.print("PM"); display.setTextColor(SSD1306_WHITE);
    display.setTextSize(1); display.setCursor(0,57); display.print("Turn=AM/PM  ENT=Save  CAN=Back");
}
void drawAlarming(){
    bool blink=(millis()/400)%2;
    display.setTextSize(2); display.setCursor(4,0); if(blink) display.print("!! ALARM !!");
    drawStatusBadge();
    display.setTextSize(1); display.setCursor(0,20);
    if(!espnowConnected)       display.print("Waiting for sensor...");
    else if(!calibDone)        display.printf("Calibrating...%d%%", map(calibCount,0,CALIB_SAMPLES,0,100));
    else                       display.printf("X%+.1f Y%+.1f Z%+.1f",gX,gY,gZ);
    int pct=map(motorProgress,0,MOTOR_MAX,0,100);
    display.setCursor(0,30); if(espnowConnected) display.printf("Move! %3d%%",pct);
    display.drawRect(0,40,102,8,SSD1306_WHITE);
    if(pct>0) display.fillRect(0,40,pct,8,SSD1306_WHITE);
    display.setCursor(0,53); display.print(espnowConnected?"Any key = force stop":"Or press key to stop");
}
void updateDisplay(){
    if(millis()-lastDisplayMillis<100) return;
    lastDisplayMillis=millis();
    display.clearDisplay(); display.setTextColor(SSD1306_WHITE);
    switch(appState){
        case STATE_SHOW:     drawShowTime(); break;
        case STATE_MENU:     drawMenu();     break;
        case STATE_SET_H:    drawSetH();     break;
        case STATE_SET_M:    drawSetM();     break;
        case STATE_SET_AMPM: drawSetAMPM();  break;
        case STATE_ALARMING: drawAlarming(); break;
    }
    display.display();
}

// ─── Setup ───────────────────────────────────────────────────
void setup(){
    Serial.begin(115200); delay(400);
    Serial.println("=== Alarm Clock + ESP-NOW ===");
    pinMode(BTN_ENTER,INPUT_PULLUP); pinMode(BTN_CANCEL,INPUT_PULLUP);
    attachInterrupt(digitalPinToInterrupt(BTN_ENTER), isrEnter, FALLING);
    attachInterrupt(digitalPinToInterrupt(BTN_CANCEL),isrCancel,FALLING);
    pinMode(LED_PIN,OUTPUT); pinMode(BUZZER_PIN,OUTPUT);
    analogReadResolution(12);
    Wire.begin(6,7);
    if(!display.begin(SSD1306_SWITCHCAPVCC,OLED_ADDR)){ Serial.println("[ERROR] OLED"); while(1) delay(500); }
    // ── Boot Splash — animated alarm clock ──────────────────────────────────
    // Draw alarm clock face + shake animation + "Wake to Shake!" text
    for (int frame = 0; frame < 18; frame++) {
        display.clearDisplay();

        // Shake offset: alternates -2, 0, +2 pixels
        int shake = 0;
        if (frame < 12) {  // shake for first 12 frames
            int s = frame % 3;
            shake = (s == 0) ? -2 : (s == 1) ? 0 : 2;
        }

        int cx = 38 + shake;   // clock center X
        int cy = 30;           // clock center Y
        int cr = 22;           // clock radius

        // Clock body (outer circle)
        display.drawCircle(cx, cy, cr, SSD1306_WHITE);
        display.drawCircle(cx, cy, cr - 1, SSD1306_WHITE);

        // Bell bumps on top
        display.fillCircle(cx - 14 + shake, cy - 20, 4, SSD1306_WHITE);
        display.fillCircle(cx + 14 + shake, cy - 20, 4, SSD1306_WHITE);

        // Clock legs on bottom
        display.fillTriangle(cx - 12 + shake, cy + cr,
                             cx - 18 + shake, cy + cr + 7,
                             cx - 6  + shake, cy + cr + 7, SSD1306_WHITE);
        display.fillTriangle(cx + 12 + shake, cy + cr,
                             cx + 6  + shake, cy + cr + 7,
                             cx + 18 + shake, cy + cr + 7, SSD1306_WHITE);

        // Hour hand (pointing ~10 o'clock)
        display.drawLine(cx, cy, cx - 8 + shake, cy - 12, SSD1306_WHITE);
        // Minute hand (pointing ~12 o'clock, slightly right)
        display.drawLine(cx, cy, cx + 3 + shake, cy - 16, SSD1306_WHITE);

        // Center dot
        display.fillCircle(cx, cy, 2, SSD1306_WHITE);

        // Vibration lines when shaking
        if (frame < 12 && frame % 2 == 0) {
            display.drawLine(cx - cr - 5 + shake, cy - 5, cx - cr - 10 + shake, cy - 8, SSD1306_WHITE);
            display.drawLine(cx - cr - 5 + shake, cy + 3, cx - cr - 10 + shake, cy + 6, SSD1306_WHITE);
            display.drawLine(cx + cr + 5 + shake, cy - 5, cx + cr + 10 + shake, cy - 8, SSD1306_WHITE);
            display.drawLine(cx + cr + 5 + shake, cy + 3, cx + cr + 10 + shake, cy + 6, SSD1306_WHITE);
        }

        // "Wake to Shake!" text on right side
        display.setTextColor(SSD1306_WHITE);
        display.setTextSize(1);
        display.setCursor(70, 18);
        display.print("Shake to");
        display.setTextSize(1);
        display.setCursor(70, 30);
        display.print("Wake!");

        // Dots animation under text
        display.setCursor(70, 44);
        for (int d = 0; d <= (frame % 4); d++) display.print(".");

        display.display();
        delay(120);
    }
    display.clearDisplay();
    display.display();

    Serial.println("[MOTOR] Zeroing...");
    motor.zero();
    Serial.println("[MOTOR] Ready");
    Serial.println("[ESP-NOW] Standby until alarm");
    lastSecMillis=millis();
    for(int i=0;i<3;i++){ digitalWrite(LED_PIN,HIGH);delay(80);digitalWrite(LED_PIN,LOW);delay(80); }
}

// ─── Loop ────────────────────────────────────────────────────
void loop(){
    motor.update();
    clockTick();
    handleInput();
    alarmEffects();
    updateStatusLed();
    updateDisplay();
    readPot();
}

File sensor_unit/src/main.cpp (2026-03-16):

/**
 * ============================================================
 *  ESP-NOW SENDER — XIAO ESP32C3 + ADXL345
 * ============================================================
 */

#include <Arduino.h>
#include <Wire.h>
#include <WiFi.h>
#include <esp_now.h>
#include <Adafruit_Sensor.h>
#include <Adafruit_ADXL345_U.h>

// ─── ✅ Updated MAC address ─────────────────────────────────
uint8_t receiverAddress[] = {0x58, 0x8C, 0x81, 0xA0, 0xBC, 0x30};

// ─── LED ────────────────────────────────────────────────────
#define LED_PIN           D3
#define MOTION_THRESHOLD  0.5f
#define LED_BLINK_MS      300

// ─── ADXL345 ───────────────────────────────────────────────
Adafruit_ADXL345_Unified accel = Adafruit_ADXL345_Unified(12345);

// ─── Data struct ────────────────────────────────────────────
typedef struct struct_message {
  float x;
  float y;
  float z;
} struct_message;

struct_message data;

// ─── Motion tracking ───────────────────────────────────────
float prevX = 0, prevY = 0, prevZ = 0;
bool firstReading = true;
unsigned long ledOnUntil = 0;

void OnDataSent(const uint8_t *mac_addr, esp_now_send_status_t status) {
  Serial.print("Send Status: ");
  Serial.println(status == ESP_NOW_SEND_SUCCESS ? "Success" : "Fail");
}

void setup() {
  Serial.begin(115200);

  pinMode(LED_PIN, OUTPUT);
  digitalWrite(LED_PIN, LOW);

  Wire.begin(D4, D5);
  Wire.setClock(100000);
  if (!accel.begin()) {
    Serial.println("[ERROR] ADXL345 not found!");
    while (1) {
      digitalWrite(LED_PIN, HIGH); delay(100);
      digitalWrite(LED_PIN, LOW);  delay(100);
    }
  }
  accel.setRange(ADXL345_RANGE_2_G);
  Serial.println("[OK] ADXL345 ready");

  WiFi.mode(WIFI_STA);
  if (esp_now_init() != ESP_OK) {
    Serial.println("ESP-NOW init failed");
    return;
  }

  esp_now_register_send_cb(OnDataSent);

  esp_now_peer_info_t peerInfo = {};
  memcpy(peerInfo.peer_addr, receiverAddress, 6);
  peerInfo.channel = 0;
  peerInfo.encrypt = false;

  if (esp_now_add_peer(&peerInfo) != ESP_OK) {
    Serial.println("Failed to add peer");
    return;
  }

  Serial.println("Sender ready");
}

void loop() {
  digitalWrite(LED_PIN, millis() < ledOnUntil ? HIGH : LOW);

  static unsigned long lastLoop = 0;
  if (millis() - lastLoop < 200) return;
  lastLoop = millis();

  sensors_event_t event;
  accel.getEvent(&event);

  data.x = event.acceleration.x;
  data.y = event.acceleration.y;
  data.z = event.acceleration.z;

  if (firstReading) {
    prevX = data.x; prevY = data.y; prevZ = data.z;
    firstReading = false;
  } else {
    float dx = fabsf(data.x - prevX);
    float dy = fabsf(data.y - prevY);
    float dz = fabsf(data.z - prevZ);
    if (dx > MOTION_THRESHOLD || dy > MOTION_THRESHOLD || dz > MOTION_THRESHOLD) {
      ledOnUntil = millis() + LED_BLINK_MS;
      Serial.printf("[MOTION] dX=%.2f dY=%.2f dZ=%.2f\n", dx, dy, dz);
    }
    prevX = data.x; prevY = data.y; prevZ = data.z;
  }

  esp_now_send(receiverAddress, (uint8_t *)&data, sizeof(data));
  Serial.printf("Sending X=%.2f  Y=%.2f  Z=%.2f\n", data.x, data.y, data.z);
}
